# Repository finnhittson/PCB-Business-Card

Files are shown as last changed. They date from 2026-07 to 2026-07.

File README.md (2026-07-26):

# PCB Business Card

This repo contains all information needed to make a PCB business card. The card features NFC IC that allows users to tap their phone and receive the stored data on the card. Ideally this card is used at recruiting events to share a resume or a portfolio while also demonstrating one’s ability to make such a card. It also doubles as a fun way to rick roll your friends. This repo has a template for users to make their own PCB business card using the KiCad files in the `electrical/` directory and the necessary software to configure the NFC tag in the `software/` directory. The image below is my personal business card, but this repo also contains steps I took to make these cards in bulk. To see a demonstration of these cards working see this [link](https://youtu.be/k8sX_htg_Z4) and to see different designs see this [link](https://youtu.be/7vKhVwrzvhk).
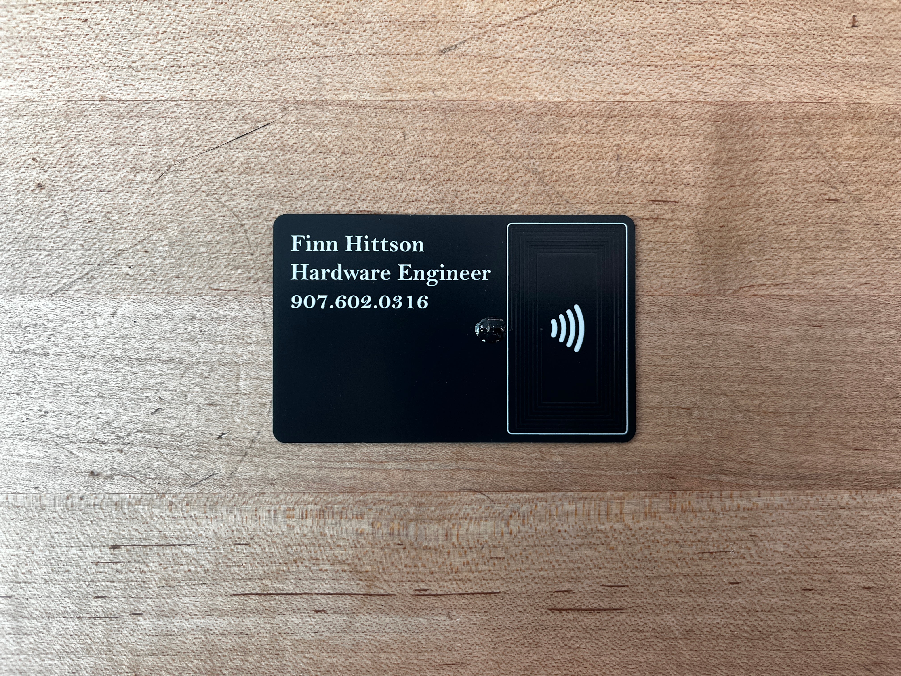
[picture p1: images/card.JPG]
card


## Electrical

The schematic for the business card is very simple consisting of 5 devices. There is a resistor and LED to add effect and ambiance to the PCB and show the result of effective energy harvesting. There is a capacitor to store energy from the coil antenna. And finally, there is the NFC IC which is responsible for harvesting the energy captured by the coil, storing the data in EEPROM, and communicating with the phone. The following is the schematic for the card drawn in KiCad.
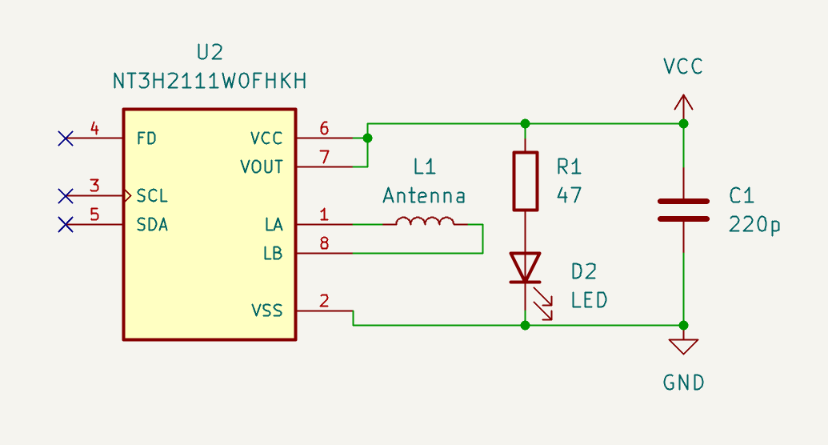
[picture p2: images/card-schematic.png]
card-schematic

The IC used for this is the [NT3H2111W0FHKH](https://www.digikey.com/en/products/detail/nxp-usa-inc/NT3H2111W0FHKH/5872977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). The most engineeringly complex part of this card is the design of the antenna. The antenna effectively is an inductor that captures the magnetic field radiated from the phone. The phone generates an oscillating magnetic field at 13.56MHz and the capacitor on the IC forms a resonant take with the inductor to maximize energy captured. Thus, to design the antenna you can use the LC resonance formula below to calculate the value of inductance required. The datasheets recommends using a 220pF capacitor and with the frequency set to 13.56MHz we can rearrange and calculate the value for L.

$f_0=\frac{1}{2\pi\sqrt{LC}}$

Going through the math it is roughly 626nH. Next is to design the physical shape of the antenna and make sure it has 626nH of inductance. There are many inductor calculators online, but I found [this](https://eds.st.com/antenna/#/) one to be most helpful. This calculator lets you give dimensions for your antenna which is very helpful since we want this on a PCB with credit card dimensions. The next thing is to make a footprint with the same dimensions that the antenna calculator created. The image below is an image of the antenna laid out on a PCB template.
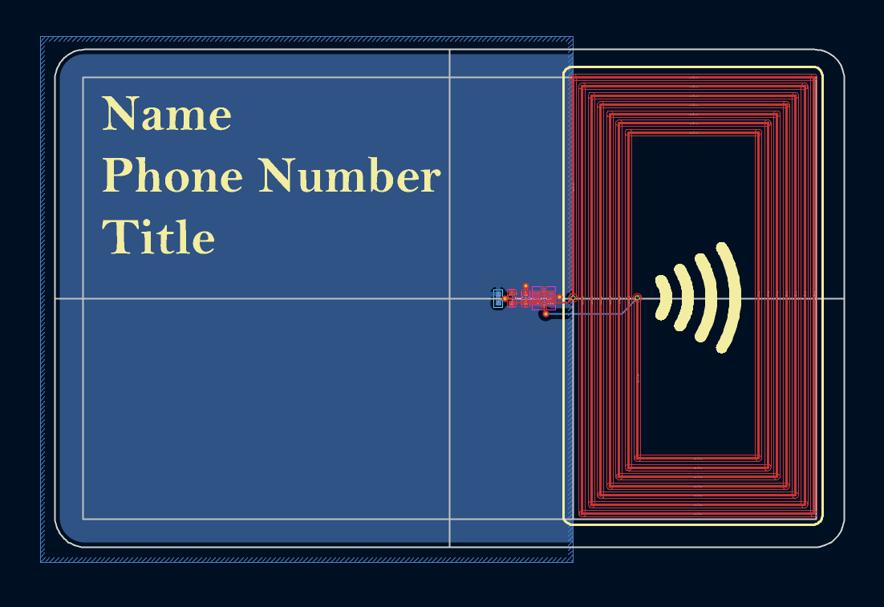
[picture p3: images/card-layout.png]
card-layout

With the PCB you can then modify the front and back silkscreen to have your name, phone number, and title. The backside can then have an image in which you can integrate an LED to add a cool effect.

## Software

Annoyingly the [NT3H2111W0FHKH](https://www.digikey.com/en/products/detail/nxp-usa-inc/NT3H2111W0FHKH/5872977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) IC come off the fab line in a read only state. I learned this the hard way when I soldered all my devices to my PCB card and couldn't write to it. To fix this I made another PCB to act as my programmer board that would unlock the ICs and then I would solder these unlocked ICs to the business cards. I wanted to use the smallest IC's possible, so the package type is an 8 pin QFN style package which is mighty small. I hot air gunned the IC to the PCB then programmed it using an Arduino as shown in the image below.
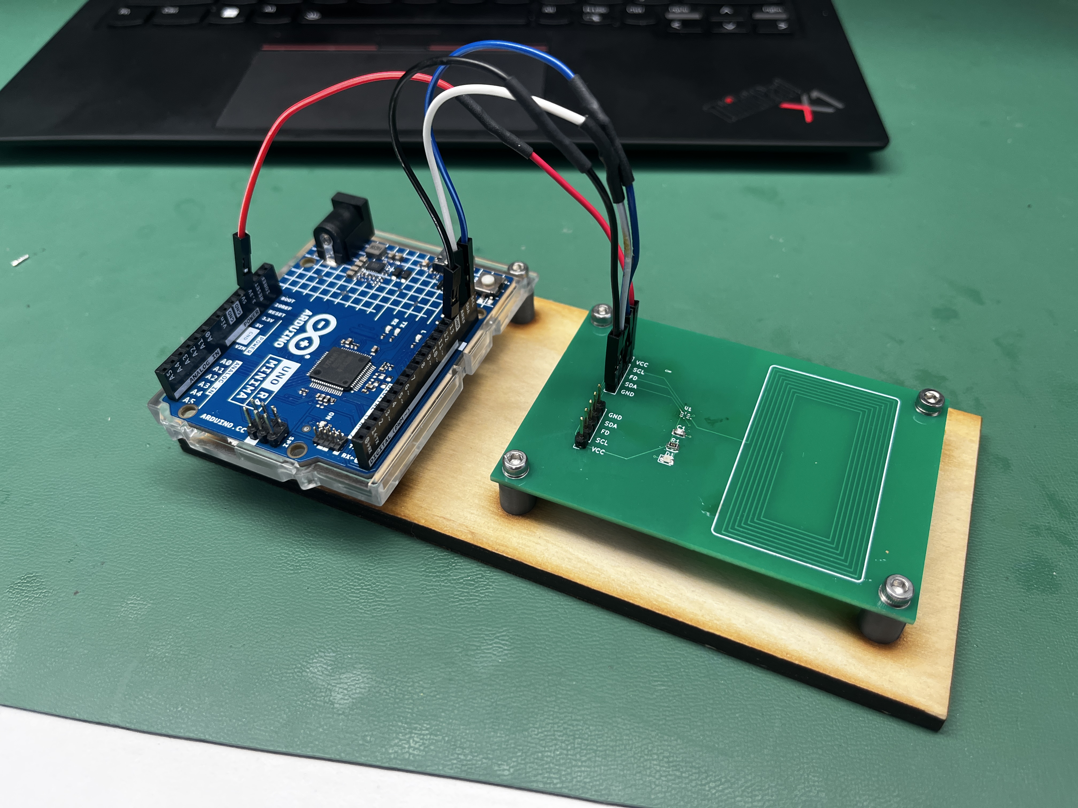
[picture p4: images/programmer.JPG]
programmer

What the Arduino code is setting is the capability container (CC), described on page 25 of the datasheet, to have read and write access. This is done by setting the registers outlined in Table 8. This gives the CC register read write access.
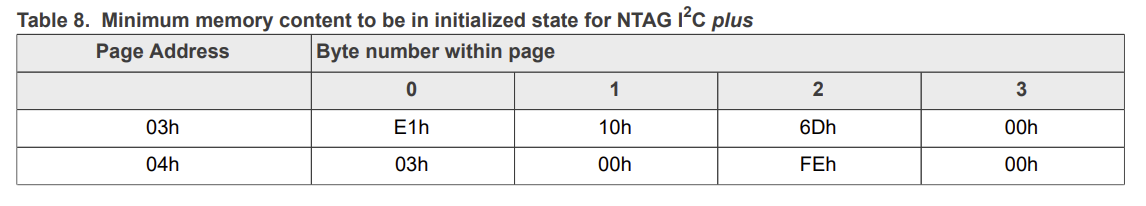
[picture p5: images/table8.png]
table8

However, because of the way memory is organized in this IC, caution needs to be taken so that you do not change other settings. When reading and writing to these registers you can only read and write to an entire page which contains more information than you need. A page at 16 bytes and we only need to modify 4 at a time. Therefore, the software reads a page, modifies the 4 bytes while leaving the other 12 unchanged, and then writes the entire page back to memory. Another caveat is that in enabling read write access for CC, the I2C address changes from 0x55 to 0x02 and you need to repeat the process twice; once for the 0x55 address and once for the 0x02 address. I found it easiest to start with the 0x55 address, verify the device was visible on the I2C bus, write my data, and repeat the process. I knew the write was successful if when I checked the I2C bus again I would see a device at 0x02 and no other address.

Once all of this was done and the unlocked IC is soldered to the board, I used NFC Tools app to program the IC to either my resume, linked account, or this [link](https://www.youtube.com/watch?v=dQw4w9WgXcQ).

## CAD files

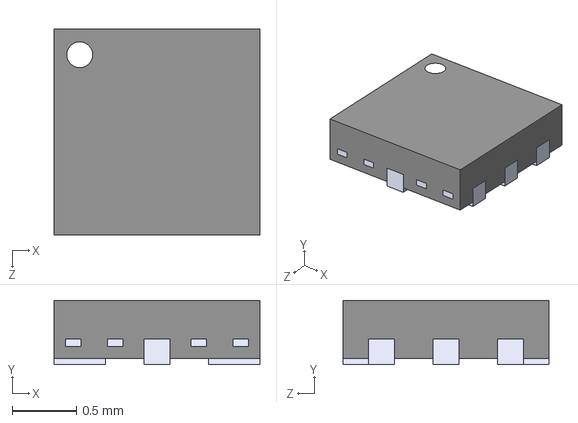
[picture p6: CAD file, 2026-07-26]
electrical/card-template/3d_models/NT3H2111W0FHKH.step
1.60 x 0.5 x 1.60 mm

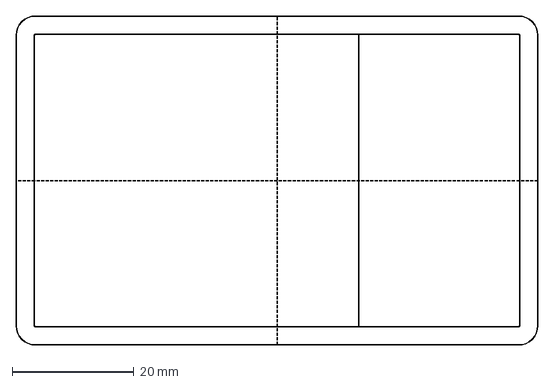
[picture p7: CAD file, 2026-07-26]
electrical/card-template/card_outline.dxf
85.6 x 54.0 mm

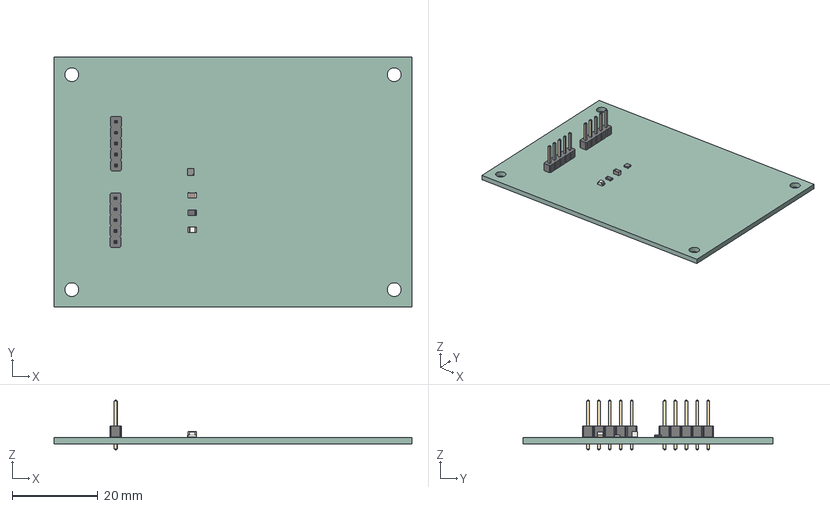
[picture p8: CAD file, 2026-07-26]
electrical/qfn-programmer/qfn-programmer.step
83.3 x 58.1 x 11.5 mm
C_0805_2012Metric
LED_0805_2012Metric
NT3H2111W0FHKH
R_0805_2012Metric
PinHeader_1x05_P2.54mm_Vertical x 2
qfn-programmer_PCB

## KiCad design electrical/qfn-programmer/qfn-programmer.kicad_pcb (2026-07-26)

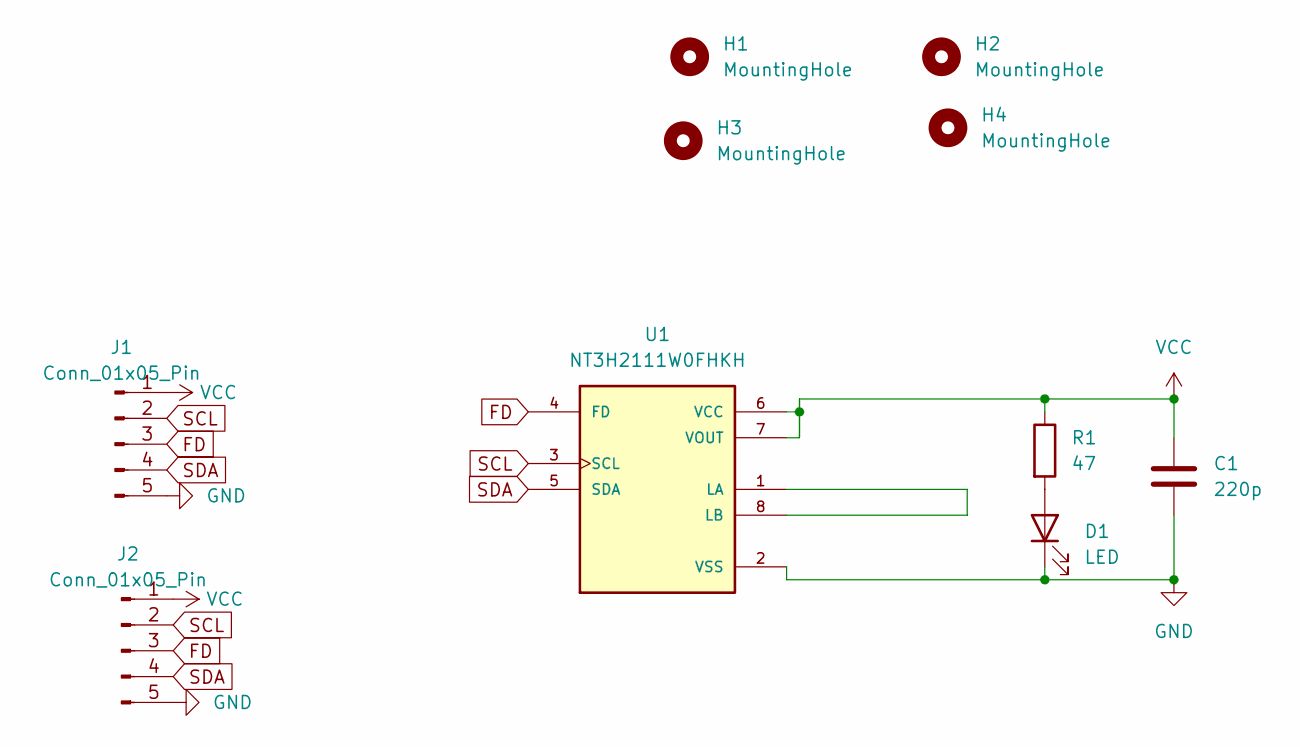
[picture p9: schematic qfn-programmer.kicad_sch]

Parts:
C1: 220p; C_0805_2012Metric
D1: LED; LED_0805_2012Metric
H1, H2, H3, H4: MountingHole; MountingHole_3.2mm_M3_DIN965_Pad_TopBottom
J1, J2: Conn_01x05_Pin; PinSocket_1x05_P2.54mm_Vertical
R1: 47; R_0805_2012Metric
U1: NT3H2111W0FHKH; QFN8P50_160X160X50L40X20N

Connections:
FD: J1.3, J2.3, U1.4 (FD)
GND: C1.2, D1.1 (K), J1.5, J2.5, U1.2 (VSS)
unnamed: D1.2 (A), R1.2
unnamed: U1.1 (LA), U1.8 (LB)
SCL: J1.2, J2.2, U1.3 (SCL)
SDA: J1.4, J2.4, U1.5 (SDA)
VCC: C1.1, J1.1, J2.1, R1.1, U1.6 (VCC), U1.7 (VOUT)

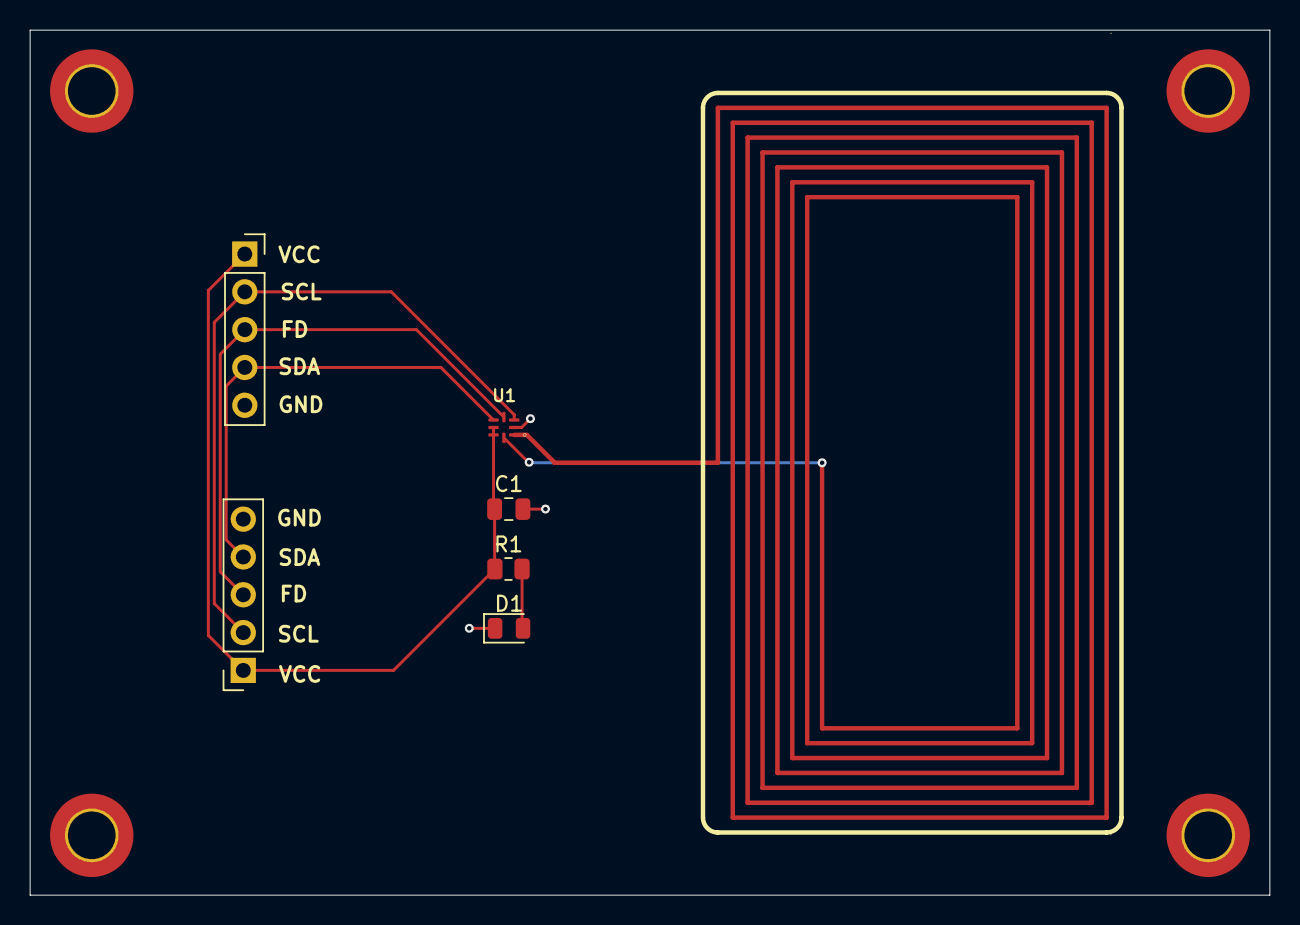
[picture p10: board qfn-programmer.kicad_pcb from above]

Board: 2 copper layers, 83.3 x 58.1 mm, 10 parts (0 on the bottom side), 7 nets.

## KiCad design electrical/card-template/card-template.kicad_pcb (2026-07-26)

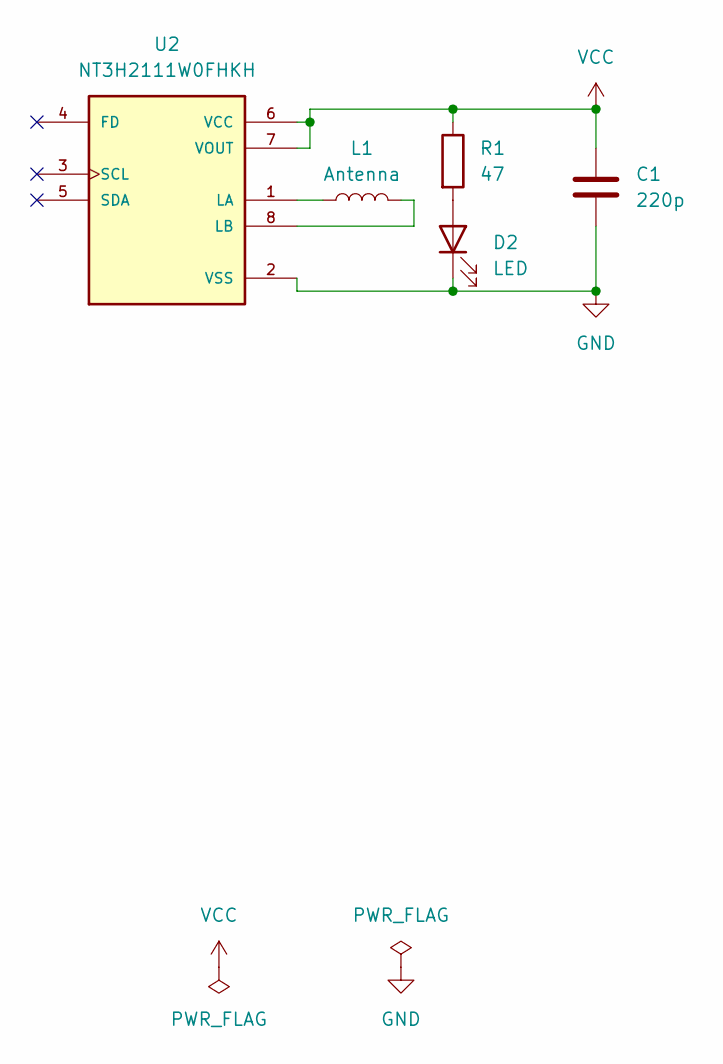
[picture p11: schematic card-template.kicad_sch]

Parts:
C1: 220p; C_0402_1005Metric
D2: LED; LED_0402_1005Metric
L1: Antenna
R1: 47; R_0402_1005Metric
U2: NT3H2111W0FHKH; QFN8P50_160X160X50L40X20N

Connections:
GND: C1.2, D2.1 (K), U2.2 (VSS)
unnamed: D2.2 (A), R1.2
unnamed: L1.1, U2.1 (LA)
unnamed: L1.2, U2.8 (LB)
VCC: C1.1, R1.1, U2.6 (VCC), U2.7 (VOUT)

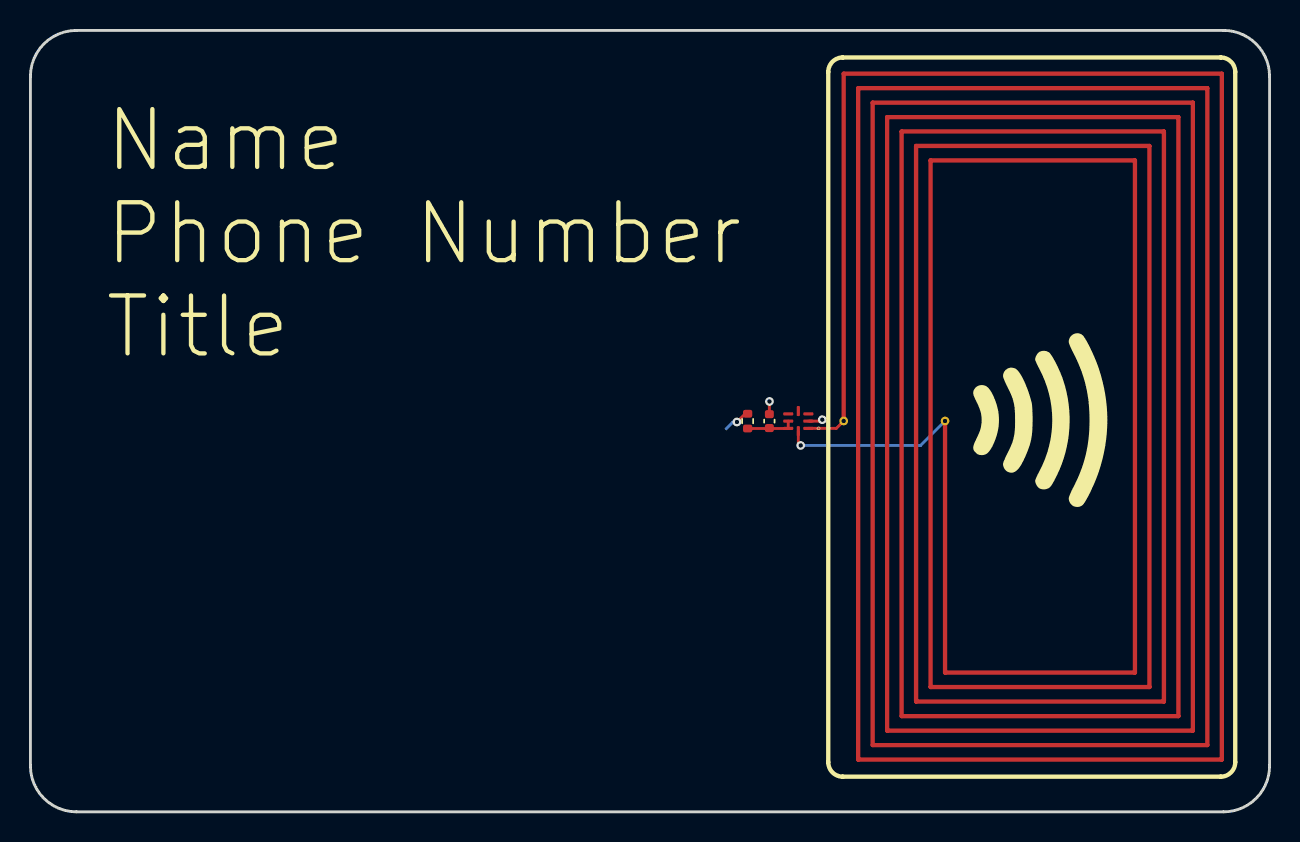
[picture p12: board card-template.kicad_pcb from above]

Board: 2 copper layers, 85.6 x 54.0 mm, 5 parts (1 on the bottom side), 5 nets.

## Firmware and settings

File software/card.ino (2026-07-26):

#include <Wire.h>

#define NFC_ADDR 0x02
#define BLK_ADDR_0 0x00
#define BLK_ADDR_1 0x01

void setup() {
  Serial.begin(9600);
  while (!Serial);

  Wire.begin();
  delay(100);

  scanI2CAddr();

  if (true) {
    uint8_t block0[16];
    block0[12] = 0xE1;
    block0[13] = 0x10;
    block0[14] = 0x6D;
    block0[15] = 0x00;
    writePage(BLK_ADDR_0, block0);
    delay(100);

    uint8_t block1[16];
    block1[0] = 0x03;
    block1[1] = 0x00;
    block1[2] = 0xFE;
    writePage(BLK_ADDR_1, block1);
    delay(100);
  }

  // here just for debugging
  if (false) {
    uint8_t block0[16];
    readPage(BLK_ADDR_0, block0);
    delay(100);

    Serial.println("Block 0 before modification");
    printArray(block0, 16);

    block0[12] = 0xE1;
    block0[13] = 0x10;
    block0[14] = 0x6D;
    block0[15] = 0x00;
    writePage(BLK_ADDR_0, block0);
    delay(100);

    readPage(BLK_ADDR_0, block0);
    delay(100);

    Serial.println("Block 0 after modification");
    printArray(block0, 16);

    uint8_t block1[16];
    readPage(BLK_ADDR_1, block1);
    delay(100);

    Serial.println("Block 1 before modification");
    printArray(block1, 16);

    for (uint8_t i = 0; i < 16; i++) {
      block1[i] = 0x00;
    }
    block1[0] = 0x03;
    block1[2] = 0xFE;
    writePage(BLK_ADDR_1, block1);
    delay(100);

    readPage(BLK_ADDR_1, block1);
    delay(100);

    Serial.println("Block 1 after modification");
    printArray(block1, 16);
  }
}

void loop() {
}

void readPage(uint8_t page, uint8_t *result) {
  Wire.beginTransmission(NFC_ADDR);
  Wire.write(page);
  Wire.endTransmission(false);
  uint8_t length = Wire.requestFrom(NFC_ADDR, (uint8_t)16);
  for (uint8_t idx = 0; idx < length && Wire.available(); idx++) {
    result[idx] = Wire.read();
  }
}

void writePage(uint8_t page, uint8_t *data) {
  Wire.beginTransmission(NFC_ADDR);
  Wire.write(page);
  for (uint8_t i = 0; i < 16; i++) {
    Wire.write(data[i]);
  }
  Wire.endTransmission();
}

void printArray(uint8_t *data, uint8_t n) {
  for (uint8_t i = 0; i < n; i++) {
    Serial.println(data[i]);
  }
  Serial.println();
}

void scanI2CAddr() {
  byte error, address;
  int devices = 0;

  // Serial.println("Scanning...");

  for (address = 1; address < 127; address++) {
    Wire.beginTransmission(address);
    error = Wire.endTransmission();
    delay(10);

    if (error == 0) {
      Serial.print("I2C device found at 0x");
      if (address < 16) Serial.print("0");
      Serial.print(address, HEX);
      Serial.println();
      devices++;
    }
    else if (error == 4) {
      Serial.print("Unknown error at 0x");
      if (address < 16) Serial.print("0");
        Serial.println(address, HEX);
    }
  }

  if (devices == 0)
    Serial.println("No I2C devices found\n");
  else
    Serial.println("Scan complete\n");
}

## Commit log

2026-07-26 Add schematic and code
    [NT3H2111W0FHKH.step, card-template.kicad_pcb, card-template.kicad_sch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]
2026-07-26 Add schematic image
2026-07-26 Add qfn project file
    [qfn-programmer-B_Cu.gbr, qfn-programmer-B_Mask.gbr, qfn-programmer-B_Paste.gbr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]
